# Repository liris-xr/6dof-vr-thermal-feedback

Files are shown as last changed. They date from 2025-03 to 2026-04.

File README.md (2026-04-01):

# 6dof-vr-thermal-feedback
<p align="center">
  Repository for the IEEE VR 2025 Poster - <b>Dynamic and Modular Thermal Feedback for Interactive 6DoF VR: Implementation and Evaluation</b>
</p>
<p align="center">
  Sophie Villenave, Pierre Raimbaud, Guillaume Lavoué
</p>
<!-- <p align="center">
  <a href="google.com">[PDF]</a> <a href="google.com">[Poster]</a>
</p> -->

## Overview
Creating ambient thermal feedback for VR experience is a challenge, and while numerous solutions in the litterature exist to provide thermal sensation, they are often very complex and under-documented. As this makes replication tedious, we propose a simple and tried system, that uses infrared lamps and fans, which can be easily controlled and is proven to provide quality thermal sensation while in VR, which is shown to enhance user quality of experience, and can also be crucial to specific applications. This repository hosts the Unity package we developed to control our thermal feedback system from a VR application. It also contains the technical documentation required to replicate the system as it is presented in the poster.

>__*New:*__ __Obstacle Awareness__ 
>
>Obstacles between the thermal source and the user will be detected and the thermal feedback will be adjusted accordingly.

## Thermal Feedback System
### Hardware Shopping List
* 4 x [300W Infrared Lamps](https://uk.rs-online.com/web/p/heat-lamps/7897909)
* 4 x Lamp Holders
* 1 x [DMX 4-Way Dimmer](https://www.thomann.co.uk/stairville_dds_405_lc_dmx_4_ch._dimmer.htm)
* 4 x [DMX Fans](https://www.thomann.co.uk/adj_entour_cyclone.htm)
* 1 x [Arduino Mega](https://store.arduino.cc/products/arduino-mega-2560-rev3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))
* 1 x USB-B 2.0 (Arduino) to USB-A or USB-C (PC) cable. Arduino Mega use **USB-B 2.0** connector, which differs from USB-B 3.0 connector.
* 1 x [DMX Shield for Arduino](https://www.digikey.co.uk/en/products/detail/dfrobot/DFR0260/7087143)
* 1 x [Shield Stack Connectors ARD85](https://www.digikey.fr/en/products/detail/adafruit-industries-llc/85/5154649)
* 2 x Jumper Wire Female to Female
* 5 x [3-pin DMX Cables](https://www.thomann.co.uk/stairville_pdc3cc_dmx_cable_50_m_3_pin.htm)

### Arduino DMX Controller
#### Requirements  
- **Arduino Mega**. Other arduino models won't work because the DMX shield uses the RX and TX ports of the board.
- **DMX Shield**
- **USB-B Cable**  
- **Arduino IDE** (download from [Arduino's official site](https://www.arduino.cc/en/software))  

#### Flashing Firmware
1. **Connect your Arduino**  
   - Plug in the Arduino via USB.  
   - Open **Arduino IDE**.  

2. **Select the Correct Board & Port**  
   - Use the dropdown to select the connected Arduino Mega.  

3. **Install Required Libraries**  
   - Open `Sketch` → `Include Library` → `Manage Libraries...`  
   - Install [DMXSerial](https://github.com/mathertel/DMXSerial)

4. **Modify DMX Serial to use RX/TX 1**
   - DMX Serial Library files can be found in the `libraries\DMXSerial\src` folder of your Arduino IDE installation.
   - Within Arduino IDE, go to `File` → `Preferences` → `Sketchbook Location` to locate the folder.
   - To free Serial Port 0 for USB connection with the computer, you need to change the port used by the DMX shield. To do so, enable the definitions for Serial Port 1 in the DMXSerial library file ``src\DMXSerial_avr.h`` by uncommenting the following line:
```
#define DMX_USE_PORT1
```

5. **Upload the Firmware**  
   - Open the provided firmware `LampFanController.ino` file. It is available in the `Arduino~` folder of the Unity Package.  
   - Click `Verify` (✔) to compile the code.  
   - Click `Upload` (→) to flash the firmware onto the Arduino.  

6. **Confirm Installation**  
   - Open `Tools` → `Serial Monitor`.  
   - Set the baud rate to **115200** (or as specified).  
   - If you see "DMX" in the monitor, the firmware is successfully installed.  

### Wiring
Plug DMX Shield on the Arduino board using the stack connectors except for the RX/TX pins. Connect the DMX Shield RX/TX pins to the Serial Port 1 RX/TX pins on the Arduino board using 2 F/F jumper wires.

### (Optionnal) 3D Printing
In the `3DPrintCase` folder, you'll find a ready to 3D print case that fits nicely the Arduino Mega and the DMX Shield. We also provide the original CAD file (created in Fusion 360). Thanks to [@eliottzim](https://www.github.com/eliottzim) for designing the case !

## Unity Package
### Prerequisites  
This package requires Unity to be configured with the **.NET Framework** because it relies on **System.IO.Ports** for Serial Port communication with the DMX controller.  

**Enable .NET Framework in your Unity Project**
1. Open `Edit` → `Project Settings` → `Player`.  
2. Under the `Other Settings` section, find `API Compatibility Level`.  
3. Set it to `.NET Framework`. 
4. Restart Unity for the changes to take effect.

### Installing via Unity Package Manager (UPM)  
1. Open your Unity project.  
2. Navigate to `Window` → `Package Manager`.  
3. Click on the `+` button (top-left) and select `Add package from git URL...`.  
4. Enter the repository Git URL:  

   ```
   https://github.com/liris-xr/6dof-vr-thermal-feedback.git
   ```  

5. Click `Add` and wait for Unity to download and install the package.  
6. Once installed, import the package's samples in your project.

## Usage
### In your scene, add:
1. Arduinio DMX Controller game object *(ArduinoDMXController.cs and OnDMXOpenHandler.cs)*. 
> Make sure to set the band rate to 115200.

2. ThemalListener.cs to the MainCamera (or to a *Capsule* 3D object attached to the XR Origin. **[Recommended]**).
3. Themal sources *(ThermalSource.cs)*. 
 >There are three types of themal sources you can choose from:
 > 
 > 1. **Envieronment:** Activate the thermal feedback uniformly no matter where the user is in the scene.
 > 2. **Fall off:** Varies the thermal feedback based on inverse square law (No spatial awareness).
 >3. **Spatial:** Like the name suggests, the thermal feedback is computed based on the scatial orientation of the user.
>
>__For Spatial source:__ In the layers dropdown, select all the layers you want the Thermal Source to detect. Make sure the layer with the Thermal Listener is included. 
>
>[Note: The layers, materials, Max Dist and turn off distance are only for Spatial Sources]

4. Themal Devices (Fans/Lights). 
>**Make sure the positions of your thermal devices in real world matches that of virtual scene.**

5. Thermal Follower *(ThermalFollower.cs)*
> Make this the parent game object for all the thermal devices in the scene and choose XR Origin for Position and Rotation to follow. This will make the thermal devices to follow the user when they move.

6. Thermal Controller *(ThermalController.cs)*
> Add to the list, all the Thermal Sources and Thermal Devices in the scene accordingly.

## Troubleshooting  
### Common Issues  
1. **System.IO.Ports Namespace Missing**  
   - Ensure **.NET Framework** is enabled in **Player Settings**.
2. **Automatic retrieval of COM port fails**
   - Ensure your project scripting backend is set to **Mono** in **Player Settings**. GetSerialPortNames() is not supported via **IL2CPP**. [Unity Forum Thread](https://discussions.unity.com/t/il2cpp-system-io-serialport-arduino/736323/5)

## License  
GPL v3  

## Citation
S. Villenave, P. Raimbaud and G. Lavoué, "Dynamic and Modular Thermal Feedback for Interactive 6DoF VR: Implementation and Evaluation," 2025 IEEE Conference on Virtual Reality and 3D User Interfaces Abstracts and Workshops (VRW), Saint Malo, France, 2025, pp. 1204-1205, doi: 10.1109/VRW66409.2025.00248.

@INPROCEEDINGS{10973033,
  author={Villenave, Sophie and Raimbaud, Pierre and Lavoué, Guillaume},
  booktitle={2025 IEEE Conference on Virtual Reality and 3D User Interfaces Abstracts and Workshops (VRW)}, 
  title={Dynamic and Modular Thermal Feedback for Interactive 6DoF VR: Implementation and Evaluation}, 
  year={2025},
  volume={},
  number={},
  pages={1204-1205},
  doi={10.1109/VRW66409.2025.00248}}

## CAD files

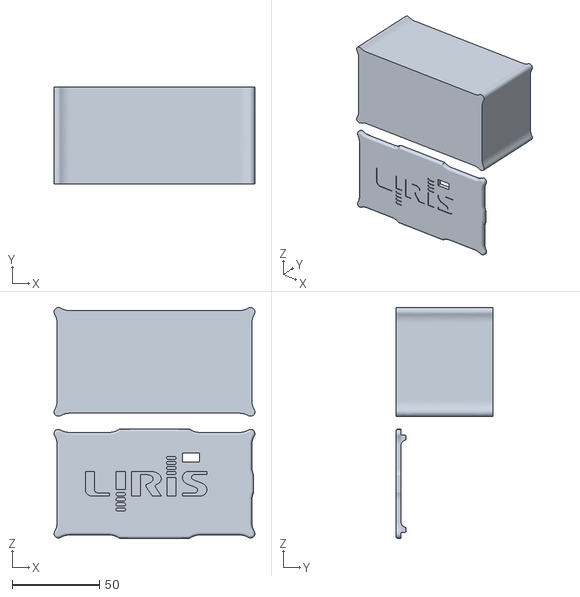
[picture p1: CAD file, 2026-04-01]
3DPrintCase~/(3D Print) Case Shield DMX Arduino Mega.stl
115.5 x 56.0 x 132.7

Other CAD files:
3DPrintCase~/(CAD) Case Shield DMX Arduino Mega.f3d

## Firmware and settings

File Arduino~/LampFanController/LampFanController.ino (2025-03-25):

#include <DMXSerial.h>

void setup() {
  DMXSerial.init(DMXController);
  Serial.begin(115200);

  while (!Serial) {
    ;
  }
  Serial.print("DMX\n");  //For handshake
}
// the loop function runs over and over again forever
void loop() {

  String serialReceived;
  if (Serial.available() > 0) {
    serialReceived = Serial.readStringUntil('\n');
    Serial.println(serialReceived);

    char *argv[8];
    int argc;
    split(argv, &argc, serialReceived.c_str(), ';', 0);
    int channel = atoi(argv[0]);
    int value = atoi(argv[1]);
    if (channel == 0) {
      for (int i = 1; i <= 512; i++) DMXSerial.write(i, value);
    } else {
      DMXSerial.write(channel, value);
    }
  }
}

char **split(char **argv, int *argc, char *string, const char delimiter, int allowempty) {
  *argc = 0;
  do {
    if (*string && (*string != delimiter || allowempty)) {
      argv[(*argc)++] = string;
    }
    while (*string && *string != delimiter) string++;
    if (*string) *string++ = 0;
    if (!allowempty)
      while (*string && *string == delimiter) string++;
  } while (*string);
  return argv;
}

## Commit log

2025-03-25 Adding Fan Lamp DMX Controller Arduino Firmware
2025-03-25 Adding wiring instructions
2025-09-02 added object awareness
    ThermalDevice and ThermalSource now change their renderer material to red or green depending on thermal intensity and collider checks. This visual feedback helps indicate when a device or source is affected by thermal interactions or blocked by objects.
2025-09-03 Add demo materials and update scene for thermal source
    Added Default, Green, Red, and Transparent materials to the demo. Updated DemoScene to use these materials and configured the ThermalSource script to use green and red materials for hit feedback. Ena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
2025-09-04 Improve usage instructions in README
    Clarified setup steps for Arduino DMX Controller and thermal devices. Added emphasis and formatting for important configuration notes to enhance readability.
2025-09-08 [Bug fixes] Refactor thermal interaction logic and player detection
    Replaced references to ThermalListener with a serialized player GameObject in ThermalSource, updating raycasting and distance calculations accordingly. Improved material assignment logic in ThermalController to handle intensity and hit detection more clearly, and added debug logging for hitPlayer state.
2025-09-08 [RayCastAll] Improve thermal detection logic and obstacle handling
    Enhanced the ThermalController and ThermalSource scripts to better handle detection of obstacles after the player. Added logic to turn off devices when obstacles are within a specified distance after the player, and refactored collider checks to use RaycastAll for more accurate detection. Also improved debug output and variable initialization for clarity.
2026-04-01 Files to 3D print the DMX Controller Case
    [(3D Print) Case Shield DMX Arduino Mega.stl, (CAD) Case Shield DMX Arduino Mega.f3d]
2026-04-01 Update README.md with 3D print instructions
